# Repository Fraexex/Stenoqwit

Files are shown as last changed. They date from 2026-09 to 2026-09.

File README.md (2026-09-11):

# Stenoqwit

## Project Owner

**Name:** Christian Galvez
**Virginia Tech Email:** chant4@vt.edu

## Project Overview

Complete circuit creation using a stenograph-like keyboard. This includes component placement, routing, user-defined symbols, and export to KiCad (no mouse or code required for the user).

## What I Hope to Learn

QMK firmware and ergonomic design is my current main focus. After I've settled on a good ergonomic design, I hope to learn more on challenges EDA tools like KiCAD are facing.

## Design and Implementation

Refer to `project_proposal_v3.pptx`

## Bill of Materials

Refer to files in `bom/`

## Timeline and Milestones

| Milestone | Target Date | Status |
|---|---|---|
| KiCAD First PCB Design | 9/11 | 100% |

## Progress Log

September 11, 2001, commemoration date

### 2026-09-11

Never forget

## Project Files

```
Stenoqwit/
├── bom/
│   ├── CPL.csv
│   ├── DigiKeyBOM.xlsx
│   └── JLCBOM.csv
├── doc/
│   └── # TODO
├── firmware/qmk/keyboards/stenoqwit/
│   ├── config.h
│   ├── keymap.c
│   └── rules.mk
├── gerber/
│   ├── stenoqwit-B_Cu.gbr
│   ├── stenoqwit-B_Mask.gbr
│   ├── stenoqwit-B_Paste.gbr
│   ├── stenoqwit-Edge_Cuts.gbr
│   ├── stenoqwit-F_Cu.gbr
│   ├── stenoqwit-F_Mask.gbr
│   ├── stenoqwit-F_Paste.gbr
│   ├── stenoqwit-F_Silkscreen.gbr
│   ├── stenoqwit-job.gbrjob
│   ├── stenoqwit-NPTH.drl
│   └── stenoqwit-PTH.drl
├── hero.png
├── project_proposal_v3.pptx
├── README.md
├── stenoqwit.kicad_pcb
├── stenoqwit.kicad_prl
├── stenoqwit.kicad_pro
└── stenoqwit.kicad_sch
```

## Useful Links

Refer to files in `doc/`

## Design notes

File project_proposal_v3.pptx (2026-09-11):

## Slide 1

Stenoqwit: Mouseless Circuit Editor
Attribute to: Christian Galvez

01 - OVERVIEW

Goal: Mouseless Visual Circuit Design

The Problem It Solves

EDA tools are mouse reliant, and is tedious navigating through complicated UI menus; schematics should be creatable at the designer’s own pace.

GOAL: Enable complete schematic capture using only a Stenoqwit
Select → Action → Adjust → Commit… all without a mouse or user coding. Place symbols, route wires, label nets, export.

SUCCESS: User can launch → place symbols with chords → connect → label → export → open in EDA

Theme: Plover Blog (Awesome Inc. by Tina Chen)

Grid System

Grid system with key-accessible coordinates for each component

User Dictionary

Common components, wiring junctions, etc., can be defined in a dictionary and recalled easily through chording

No Mouse

Every operation works through keypresses/chording only.

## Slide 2

Stenoqwit: Mouseless Circuit Editor
Attribute to: Christian Galvez

Interaction Loop

02 - OVERVIEW

SELECT COORDINATE

CHOOSE ACTION

ADJUST WITH KEYS

COMMIT

KEY BINDING EXAMPLES (configurable)

1

GRID VIEWPORT EX

https://github.com/puqeko/circuits.git

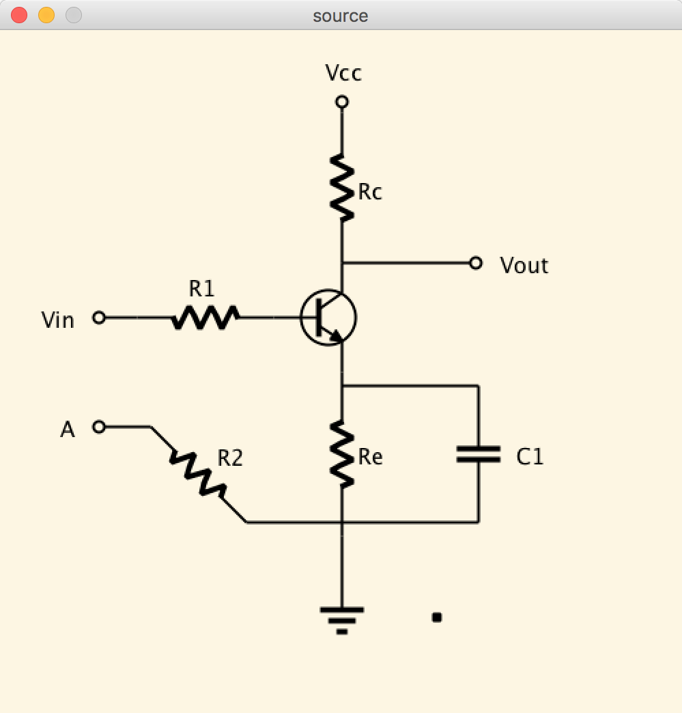
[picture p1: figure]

2

▼

3

▼

4

▼

wire

rotate

flip

cycle / select

text

undo

save / export

W-R

SR-R

F-P

-T

-U

-S

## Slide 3

Stenoqwit: Mouseless Circuit Editor
Attribute to: Christian Galvez

03 - HARDWARE

Schematic

KICAD SCHEMATIC

SPECIFICATION

23 Cherry MX2A
+ 2u stabilizer

23 1N4148W SOD-123
protection

SparkFun Qwiic
Pro Micro USB-C (ATmega32U4)

3 rows × 10 cols
MATRIX_ROW_PINS PD4/0/1

Keys

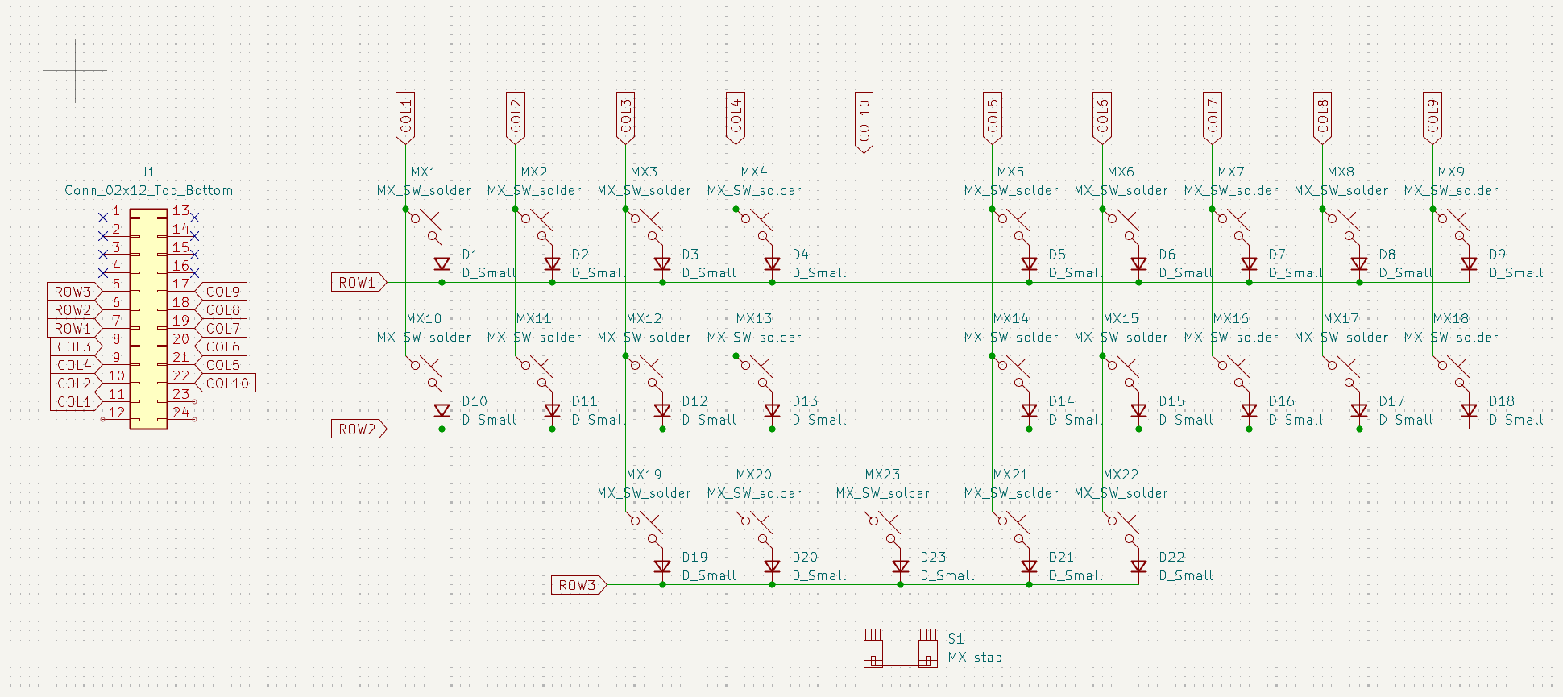
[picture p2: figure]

Diodes

MCU

Matrix

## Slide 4

Stenoqwit: Mouseless Circuit Editor
Attribute to: Christian Galvez

04 - VALUE

Why This Matters

A keyboard-first EDA workflow builds rare, transferable skills — and makes schematic capture accessible.

ACCESSIBILITY & ERGONOMICS

Full schematic capture without a mouse. Good for users with arthritis/wrist mobility issues

No mouse dependency

Minimal hand travel & strain

TECHNICAL SKILLS

Hardware, firmware, EDA, and software architecture in one project.

KiCad schematic & PCB design

QMK firmware & matrix scanning

Rust architecture

Data modeling & export

EDUCATIONAL IMPACT

A teaching platform for chorded key-inputs, human-computer interaction, and open-hardware product design.

Steno theory & dictionary design

State-machine

Test frameworks

OPEN & REUSABLE

Everything is open: spec, firmware, PCB, and editor. User dictionaries & macros compound community value.

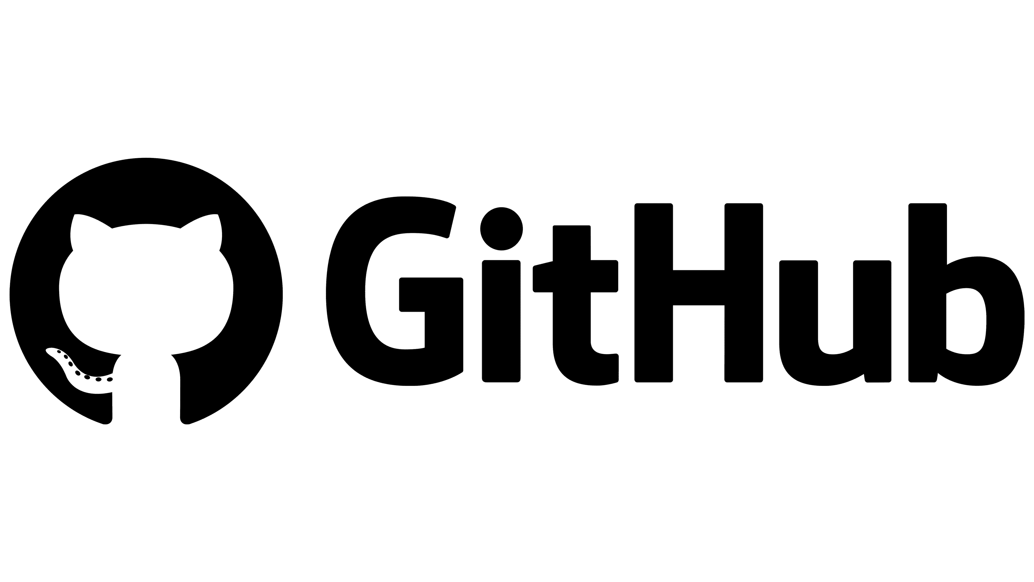
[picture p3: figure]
GitHub Logo, symbol, meaning, history, PNG, brand

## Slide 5

Stenoqwit: Mouseless Circuit Editor
Attribute to: Christian Galvez

05 - COMPONENT COST

Bill of Materials (BOM)

Component | Qty | Per Unit | Total
Cherry MX2A Brown (1644-MX2A-G1NB) | 23 | $1.75 | $40.25
1N4148W SOD-123 diodes (1655-1N4148W) | 23 | $0.06 | $1.36
SparkFun Qwiic Pro Micro USB-C | 1 | $23.95 | $23.95
MX 2u Stabilizer (S1) | 1 | $1.50 | $1.50
Pin headers TS-112-T-A-1 | 2 | $2.35 | $4.70
PCB (JLCPCB HASL-LF) | 3 | $4.00 | $12.00
Case / Plate (3D-printed or FR4) | 1 | - | -
USB-C cable | 1 | - | -
Screws, misc components | As needed | - | -
TOTAL COST | | | $86.26

*Refer to .xlsx for more details. Shipping & tariffs not included

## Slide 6

Stenoqwit: Mouseless Circuit Editor
Attribute to: Christian Galvez

06 - TIMELINE

Timeline

GANTT CHART

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
PHASE 1

Terminal

Terminal output to verify hardware key presses

PHASE 2

Usability

Command palette, fuzzy
search, labels, selection
cycling, copy/paste

PHASE 3

Stenographic keying

Simultaneous / sequential / held chording, preview, user dictionary…

PHASE 4

Schematic design

Connectivity graph,
junction validation,
reference numbering

PHASE 5

Export to EDA (stretch goal)

Export to .kicad_sch, footprints, other additional fixtures,…

HARDWARE

PCB fab
Ergonomics

Order → Build → Test → Order

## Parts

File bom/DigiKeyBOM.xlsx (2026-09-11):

Country of Origin may be different at time of shipment.
The HTSUS and ECCN information shown is for informational purposes only and is not a representation or warranty as to the accuracy or reliability of these classifications. All information is provided "as is" and is subject to change without notice. Any use made of the information provided is without recourse to Digi-Key and at the user's risk.
Index | Manufacturer Part Number | Manufacturer Name | Description | Lead Time | Availability | Stock Status | Attrition % | Requested Quantity 1 | Pack Quantity 1 | Pack Type 1 | Digi-Key Part Number 1 | Unit Price 1 | Extended Price 1 | Minimum Order Quantity 1 | Customer Reference | Requested Part Number | Lead Weeks | Datasheet | Reference Designator | US Import Tariff | Note | Part Status | RoHS Status | Moisture Sensitivity Level (MSL) | ECCN | HTSUS | Country of Origin | Environmental Information | Original Part numbers | Unit of Measure | Image | Product Notes
1 | 1N4148W | SMC Diode Solutions | DIODE STANDARD 75V 250MA SOD123 |  | 145,096 | In Stock |  | 50 | 50 | Cut Tape (CT) | 1655-1N4148WCT-ND | 0.05920 | $2.96 | 1 |  | 1655-1N4148WCT-ND | 8 | https://www.smc-diodes.com/propdf/1N4148W%20N0571%20REV.E.pdf |  | May apply on shipments to the U.S. |  | Active | ROHS3 Compliant | 1 (Unlimited) | EAR99 | 8541.10.0070 | China | https://www.smc-diodes.com/uploadfile/Declaration%20Letter%20for%20EU%20REACH-3.pdf|https://www.smc-diodes.com/uploadfile/ROHS%20Declaration%20Letter-4.pdf | 1655-1N4148WCT-ND | Each | https://mm.digikey.com/Volume0/opasdata/d220001/medias/images/6155/1655%7ESOD123%7E%7E2.jpg
2 | 15795 | SparkFun Electronics | SPARKFUN QWIIC PRO MICRO - USB-C |  | 276 | In Stock |  | 2 | 2 | Bulk | 1568-15795-ND | 23.95000 | $47.90 | 1 |  | 1568-15795-ND | 12 | https://cdn.sparkfun.com/assets/learn_tutorials/1/1/1/4/QwiicProMicroUSB-C.pdf |  | N/A |  | Active | ROHS3 Compliant | 1 (Unlimited) | EAR99 | 8471.50.0150 | China |  | 1568-15795-ND | Each | https://mm.digikey.com/Volume0/opasdata/d220001/medias/images/212/MFG_DEV-15795.jpg
3 | TS-112-T-A-1 | Samtec Inc. | CONN HDR .100" 12POS |  | 62 | In Stock |  | 4 | 4 | Tube | TS-112-T-A-1-ND | 2.35000 | $9.40 | 1 |  | TS-112-T-A-1-ND | 4 | https://mm.digikey.com/Volume0/opasdata/d220001/medias/docus/6129/tx-1xx-x-x-mkt1.pdf |  | May apply on shipments to the U.S. |  | Active | ROHS3 Compliant | 1 (Unlimited) | EAR99 | 8536.69.4040 | Malaysia |  | TS-112-T-A-1-ND | Each | https://mm.digikey.com/Volume0/opasdata/d220001/medias/images/4842/TS-112-T-A-1.jpg
4 | MX2A-G1NB | Cherry Americas LLC | MX RGB, BROWN STEM, FULL TRAVEL |  | 623 | In Stock |  | 46 | 46 | Bag | 1644-MX2A-G1NB-ND | 1.75000 | $80.50 | 1 |  | 1644-MX2A-G1NB-ND | 13 | https://www.cherrymx.de/_Resources/Persistent/b/3/5/4/b354b7275b9afb1f1a1a69b45b317057791cd38a/Data_sheet_MX2A_Red.pdf |  | May apply on shipments to the U.S. |  | Active | ROHS3 Compliant | 1 (Unlimited) | EAR99 | 8536.50.9031 | Germany |  | 1644-MX2A-G1NB-ND | Each | https://mm.digikey.com/Volume0/opasdata/d220001/derivates/6/001/196/960/MX2A-G1NB_web%28640x640%29.jpg

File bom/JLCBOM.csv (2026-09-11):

Comment | Designator | Footprint | JLCPCB Part #（optional）
D_Small | D1, D2, D3, D4, D5, D6, D7, D8, D9, D10, D11, D12, D13, D14, D15, D16, D17, D18, D19, D20, D21, D22, D23 | D_SOD-123
Conn_02x12_Top_Bottom | J1 | ProMicro_USBup
MX_SW_solder | MX1, MX2, MX3, MX4, MX5, MX6, MX7, MX8, MX9, MX10, MX11, MX12, MX13, MX14, MX15, MX16, MX17, MX18, MX19, MX20, MX21, MX22, MX23 | SW_MX_1u
MX_stab | S1 | STAB_MX_P_2u

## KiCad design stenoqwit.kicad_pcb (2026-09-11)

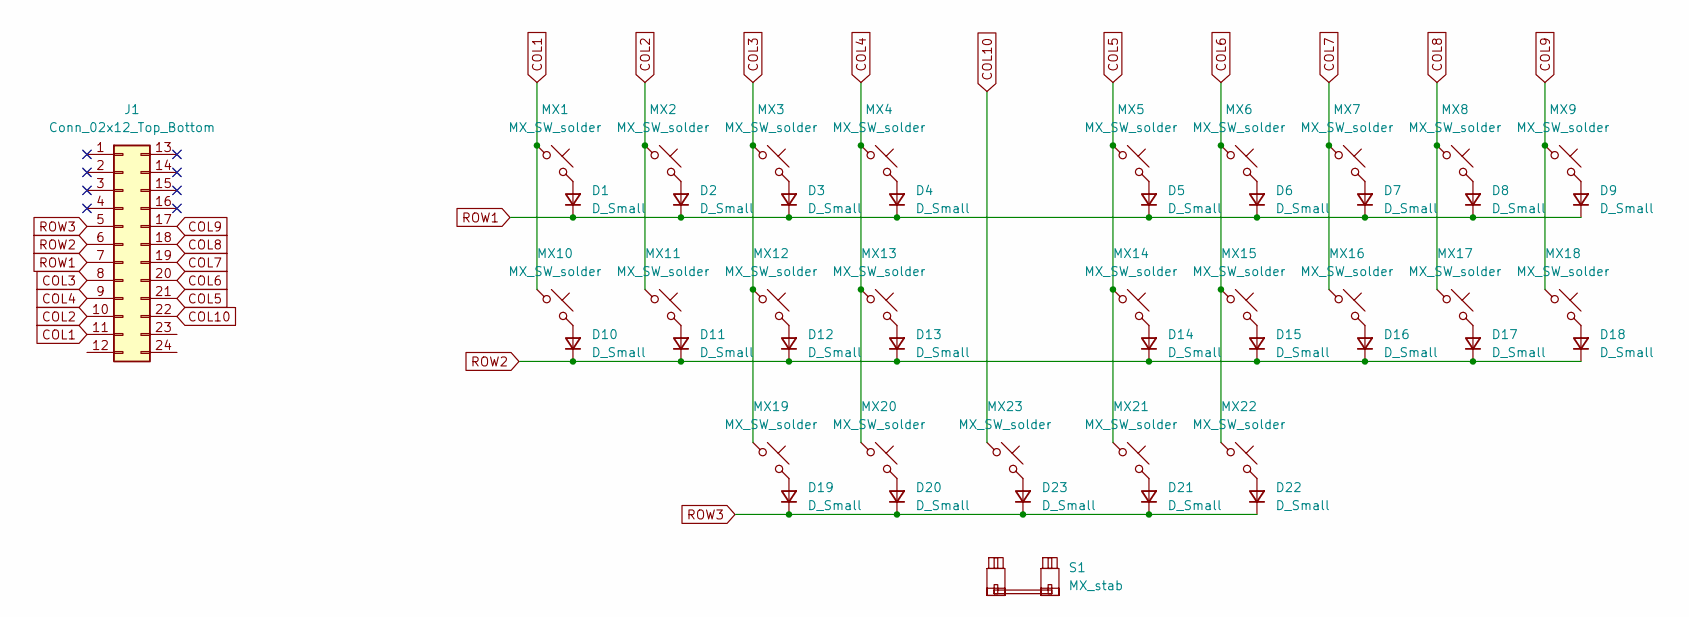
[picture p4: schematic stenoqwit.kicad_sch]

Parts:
D1, D2, D3, D4, D5, D6, D7, D8, D9, D10, D11, D12, D13, D14, D15, D16, D17, D18, D19, D20, D21, D22, D23: D_Small; D_SOD-123
J1: Conn_02x12_Top_Bottom; ProMicro_USBup
MX1, MX2, MX3, MX4, MX5, MX6, MX7, MX8, MX9, MX10, MX11, MX12, MX13, MX14, MX15, MX16, MX17, MX18, MX19, MX20, MX21, MX22, MX23: MX_SW_solder; SW_MX_1u
S1: MX_stab; STAB_MX_P_2u

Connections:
COL1: J1.11, MX1.1, MX10.1
COL2: J1.10, MX2.1, MX11.1
COL3: J1.8, MX3.1, MX12.1, MX19.1
COL4: J1.9, MX4.1, MX13.1, MX20.1
COL5: J1.21, MX5.1, MX14.1, MX21.1
COL6: J1.20, MX6.1, MX15.1, MX22.1
COL7: J1.19, MX7.1, MX16.1
COL8: J1.18, MX8.1, MX17.1
COL9: J1.17, MX9.1, MX18.1
COL10: J1.22, MX23.1
unnamed: D1.2 (A), MX1.2
unnamed: D2.2 (A), MX2.2
unnamed: D3.2 (A), MX3.2
unnamed: D4.2 (A), MX4.2
unnamed: D5.2 (A), MX5.2
unnamed: D6.2 (A), MX6.2
unnamed: D7.2 (A), MX7.2
unnamed: D8.2 (A), MX8.2
unnamed: D9.2 (A), MX9.2
unnamed: D10.2 (A), MX10.2
unnamed: D11.2 (A), MX11.2
unnamed: D12.2 (A), MX12.2
unnamed: D13.2 (A), MX13.2
unnamed: D14.2 (A), MX14.2
unnamed: D15.2 (A), MX15.2
unnamed: D16.2 (A), MX16.2
unnamed: D17.2 (A), MX17.2
unnamed: D18.2 (A), MX18.2
unnamed: D19.2 (A), MX19.2
unnamed: D20.2 (A), MX20.2
unnamed: D21.2 (A), MX21.2
unnamed: D22.2 (A), MX22.2
unnamed: D23.2 (A), MX23.2
ROW1: D1.1 (K), D2.1 (K), D3.1 (K), D4.1 (K), D5.1 (K), D6.1 (K), D7.1 (K), D8.1 (K), D9.1 (K), J1.7
ROW2: D10.1 (K), D11.1 (K), D12.1 (K), D13.1 (K), D14.1 (K), D15.1 (K), D16.1 (K), D17.1 (K), D18.1 (K), J1.6
ROW3: D19.1 (K), D20.1 (K), D21.1 (K), D22.1 (K), D23.1 (K), J1.5

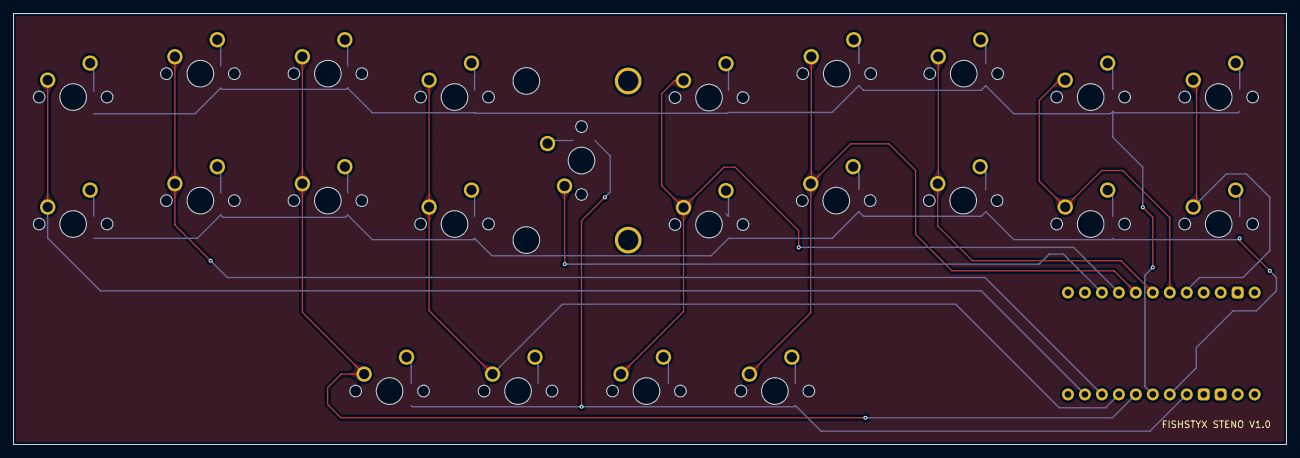
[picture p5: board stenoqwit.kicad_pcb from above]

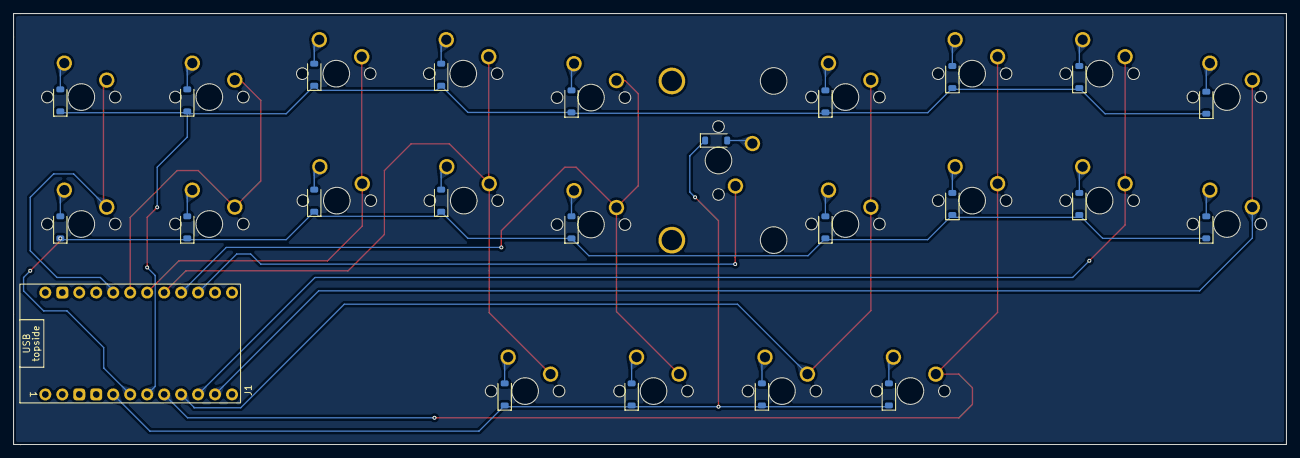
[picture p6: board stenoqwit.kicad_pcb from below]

Board: 2 copper layers, 190.5 x 64.5 mm, 48 parts (24 on the bottom side), 36 nets.
